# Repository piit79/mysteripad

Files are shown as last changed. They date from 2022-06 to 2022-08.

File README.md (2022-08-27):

# Mysteripad

#### WARNING: This project is a work in progress and hasn't been validated yet.

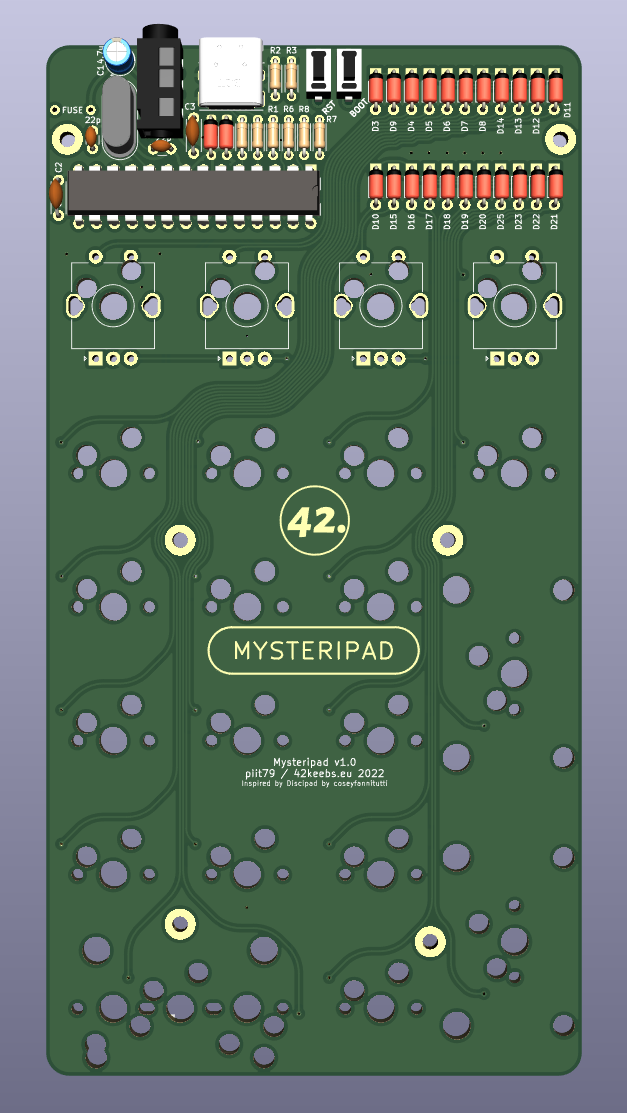
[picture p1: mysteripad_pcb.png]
Mysteripad PCB


Mysteripad is a through-hole numeric keyboard (or "numpad") matching the form 
factor of the [Mysterium keyboard]((https://github.com/piit79/mysterium)) 
([original](https://github.com/coseyfannitutti/mysterium)), much like the 
[Discipad](https://github.com/piit79/discipad) 
([original](https://github.com/coseyfannitutti/discipad)) matches the 
[Discipline](https://github.com/piit79/discipline) 
([original](https://github.com/coseyfannitutti/discipline)).

Mysteripad was inspired by (but is not based on) the [Discipad](https://github.com/coseyfannitutti/discipad) by Bryan of [cftkb.com](https://cftkb.com/).

## Features

* 17-22 keys, 0-4 rotary encoders (6 rows, 4 columns)
* Hotswappable using Kailh/Gateron hotswap sockets
* All 4 top row positions support either a switch or an EC11 rotary encoder - 4 encoders can be installed at the same time¹
* Optional split 0 support (2x 1u instead of 2u)
* TRRS socket for connection to the next 42. Keebs revision of the Mysterium (V1.5e) via a 4-pin AUX (TRRS) cable (using the I²C bus) so that a single USB cable can be used for both keyboards, similar to split keyboards

¹ To reduce the number of required I/O pins from 8 to 5, any two adjacent encoders share an I/O pin. Therefore, rotating any such encoders at higher speed simultaneously might not work correctly. Other combinations (1-3, 1-4, 2-4) should not be affected.

## Documentation

[Bill of Materials](https://github.com/piit79/mysteripad/tree/main/doc#bill-of-materials)
and [build guide](https://github.com/piit79/mysteripad/tree/main/doc#build-guide) (coming soon)

## Firmware

QMK firmware can be found in [42. Keebs QMK fork](https://github.com/piit79/qmk_firmware/tree/master/keyboards/42keebs/mysteripad).

## Kit availability

You can grab the Gerber zip files from [releases](https://github.com/piit79/mysteripad/releases) 
(coming soon), have the PCBs made at one of the fabs and order all the 
[electronic components](https://github.com/piit79/mysteripad/tree/main/doc#bill-of-materials)
at your favourite electronics store.

A complete kit will also be available from [42. Keebs](https://42keebs.eu/shop/kits/with-discrete-mcu/mysteripad-hotswap-numpad-kit-black-white/) sooner or later (probably in ~~July~~ September 2022).

## TODO

* ~~Add PCB bottom plate~~
* ~~Add PCB switch plate~~
* ~~Add acrylic cover drawing~~
* ~~Create QMK firmware~~
* Add Gerber zip files to releases
* ~~Add BOM~~
* Add build guide

## Revision history

* v1.0 (26/06/2022) - Initial version

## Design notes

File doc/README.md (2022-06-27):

# Mysteripad Documentation

## Bill of Materials

| Reference | Quantity | Description |
|---|---:|---|
| U1 | 1 | ATmega328p-PU microcontroller
| USB1 | 1 | GCT USB4085-GF-A USB-C socket
| J1 | 1 | PJ-320A 3.5 mm 4-pole AUX (TRRS) socket
| Y1 | 1 | 16 MHz crystal
| F1 | 1 | 500 mA resettable fuse (polyfuse)
| C1 | 1 | 4.7 µF electrolytic capacitor RM1.5
| C2, C3 | 2 | 0.1 µF ceramic capacitor RM5.08
| C4, C5 | 2 | 22 pF ceramic capacitor RM2.5
| R1 | 1 | 1.5 kΩ 1/6 W resistor
| R2, R3, R7, R8 | 4 | 5.1 kΩ 1/6 W resistor
| R4, R5 | 2 | 75 Ω 1/6 W resistor
| R6 | 1 | 10 kΩ 1/6 W resistor
| D1, D2 | 2 | 3.6 V Zener diode
| D3-D25 | 22 | 1N4148 diode

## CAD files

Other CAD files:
mysteripad_acrylic_cover.dxf

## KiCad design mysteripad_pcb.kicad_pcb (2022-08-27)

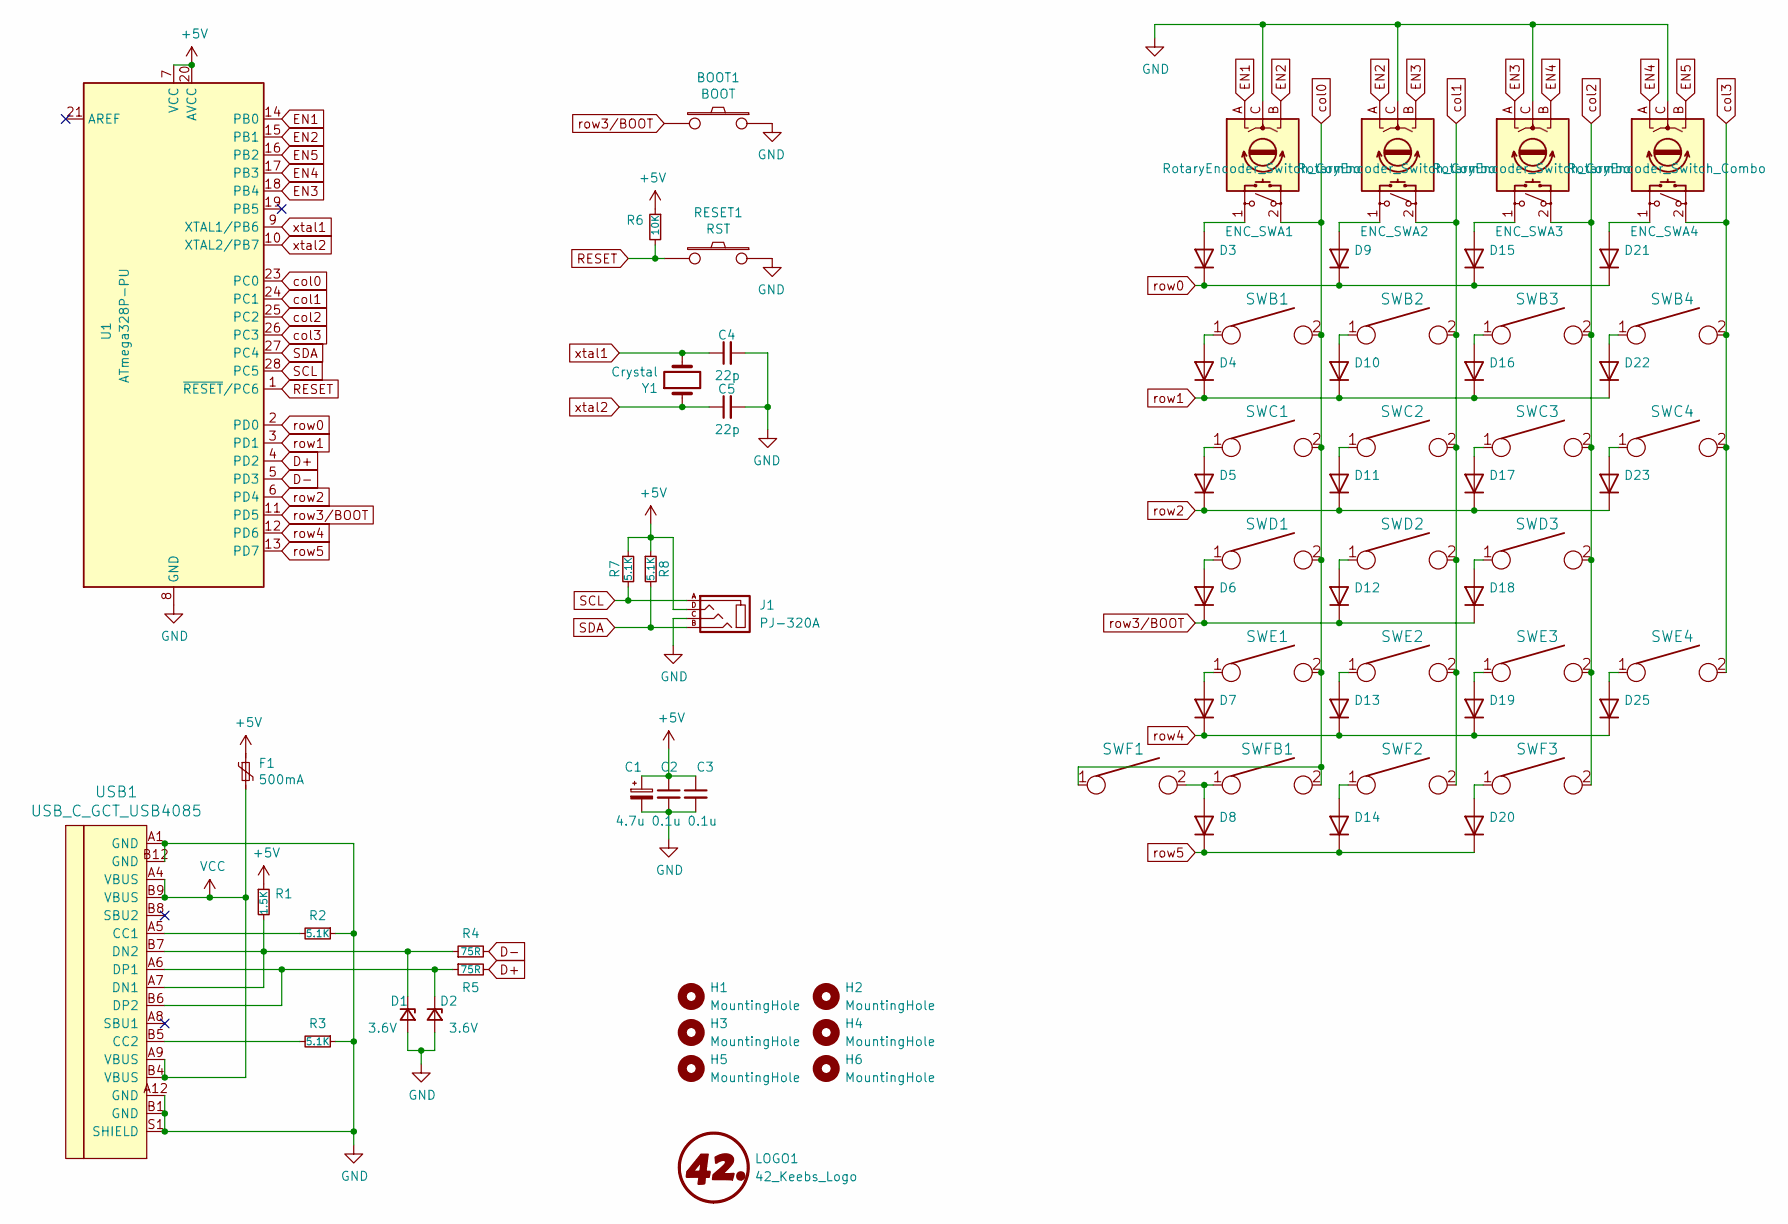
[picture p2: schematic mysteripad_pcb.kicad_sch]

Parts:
BOOT1: BOOT; ResetSW_1side
C1: 4.7u; CP_Radial_D4.0mm_P1.50mm
C2, C3: 0.1u; C_Disc_D4.3mm_W1.9mm_P5.00mm
C4, C5: 22p; C_Disc_D3.0mm_W1.6mm_P2.50mm
D1, D2: 3.6V; ZD_DO-35_SOD27_P5.08mm_Horizontal_smaller
D3, D4, D5, D6, D7, D8, D9, D10, D11, D12, D13, D14, D15, D16, D17, D18, D19, D20, D21, D22, D23, D25: D_DO-35_SOD27_P5.08mm_Horizontal
ENC_SWA1, ENC_SWA2, ENC_SWA3, ENC_SWA4: RotaryEncoder_Switch_Combo; Kailh_MX_Socket-plus-EC11-encoder
F1: 500mA; polyfuse_5.1mm
H1, H2, H3, H4, H5, H6: MountingHole; MountingHole_2.2mm_M2_Pad
J1: PJ-320A
LOGO1: 42_Keebs_Logo; 42Keebs-icon-10mm-Mask
R1: 1.5K; R_Axial_DIN0204_L3.6mm_D1.6mm_P5.08mm_Horizontal
R2, R3, R7, R8: 5.1K; R_Axial_DIN0204_L3.6mm_D1.6mm_P5.08mm_Horizontal
R4, R5: 75R; R_Axial_DIN0204_L3.6mm_D1.6mm_P5.08mm_Horizontal
R6: 10K; R_Axial_DIN0204_L3.6mm_D1.6mm_P5.08mm_Horizontal
RESET1: RST; ResetSW_1side
SWB1, SWB2, SWB3, SWB4: KEYSW; Kailh_MX_Socket-swapped-pads
SWC1, SWC2, SWC3: KEYSW; Kailh_MX_Socket-swapped-pads
SWC4: KEYSW; Kailh_MX_Socket-2u-swapped-pads-reversed-stabilizer
SWD1, SWD2, SWD3: KEYSW; Kailh_MX_Socket-swapped-pads
SWE1, SWE2, SWE3: KEYSW; Kailh_MX_Socket-swapped-pads
SWE4: KEYSW; Kailh_MX_Socket-2u-swapped-pads-reversed-stabilizer
SWF1, SWF2, SWF3: KEYSW; Kailh_MX_Socket-swapped-pads
SWFB1: KEYSW; Kailh_MX_Socket-2u-swapped-pads-reversed-stabilizer
U1: ATmega328P-PU; DIP-28_W7.62mm
USB1: USB_C_GCT_USB4085; USB_C_GCT_USB4085-offset-pads
Y1: Crystal; Crystal_HC49-4H_Vertical

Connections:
+5V: C1.1, C2.1, C3.1, F1.1, J1.D, R1.1, R6.1, R7.1, R8.1, U1.7 (VCC), U1.20 (AVCC)
D+: R5.2, U1.4 (PD2)
D-: R4.2, U1.5 (PD3)
EN1: ENC_SWA1.A, U1.14 (PB0)
EN2: ENC_SWA1.B, ENC_SWA2.A, U1.15 (PB1)
EN3: ENC_SWA2.B, ENC_SWA3.A, U1.18 (PB4)
EN4: ENC_SWA3.B, ENC_SWA4.A, U1.17 (PB3)
EN5: ENC_SWA4.B, U1.16 (PB2)
GND: BOOT1.1, C1.2, C2.2, C3.2, C4.2, C5.2, D1.2 (A), D2.2 (A), ENC_SWA1.C, ENC_SWA2.C, ENC_SWA3.C, ENC_SWA4.C, J1.C, R2.1, R3.1, RESET1.1, U1.8 (GND), U1.22 (GND), USB1.A1 (GND), USB1.A12 (GND), USB1.B1 (GND), USB1.B12 (GND), USB1.S1 (SHIELD)
unnamed: D1.1 (K), R1.2, R4.1, USB1.A7 (DN1), USB1.B7 (DN2)
unnamed: D2.1 (K), R5.1, USB1.A6 (DP1), USB1.B6 (DP2)
unnamed: D3.2 (A), ENC_SWA1.1
unnamed: D4.2 (A), SWB1.1
unnamed: D5.2 (A), SWC1.1
unnamed: D6.2 (A), SWD1.1
unnamed: D7.2 (A), SWE1.1
unnamed: D8.2 (A), SWF1.2, SWFB1.1
unnamed: D9.2 (A), ENC_SWA2.1
unnamed: D10.2 (A), SWB2.1
unnamed: D11.2 (A), SWC2.1
unnamed: D12.2 (A), SWD2.1
unnamed: D13.2 (A), SWE2.1
unnamed: D14.2 (A), SWF2.1
unnamed: D15.2 (A), ENC_SWA3.1
unnamed: D16.2 (A), SWB3.1
unnamed: D17.2 (A), SWC3.1
unnamed: D18.2 (A), SWD3.1
unnamed: D19.2 (A), SWE3.1
unnamed: D20.2 (A), SWF3.1
unnamed: D21.2 (A), ENC_SWA4.1
unnamed: D22.2 (A), SWB4.1
unnamed: D23.2 (A), SWC4.1
unnamed: D25.2 (A), SWE4.1
unnamed: R2.2, USB1.A5 (CC1)
unnamed: R3.2, USB1.B5 (CC2)
RESET: R6.2, RESET1.2, U1.1 (~RESET/PC6)
SCL: J1.A, R7.2, U1.28 (PC5)
SDA: J1.B, R8.2, U1.27 (PC4)
VCC: F1.2, USB1.A4 (VBUS), USB1.A9 (VBUS), USB1.B4 (VBUS), USB1.B9 (VBUS)
col0: ENC_SWA1.2, SWB1.2, SWC1.2, SWD1.2, SWE1.2, SWF1.1, SWFB1.2, U1.23 (PC0)
col1: ENC_SWA2.2, SWB2.2, SWC2.2, SWD2.2, SWE2.2, SWF2.2, U1.24 (PC1)
col2: ENC_SWA3.2, SWB3.2, SWC3.2, SWD3.2, SWE3.2, SWF3.2, U1.25 (PC2)
col3: ENC_SWA4.2, SWB4.2, SWC4.2, SWE4.2, U1.26 (PC3)
row0: D3.1 (K), D9.1 (K), D15.1 (K), D21.1 (K), U1.2 (PD0)
row1: D4.1 (K), D10.1 (K), D16.1 (K), D22.1 (K), U1.3 (PD1)
row2: D5.1 (K), D11.1 (K), D17.1 (K), D23.1 (K), U1.6 (PD4)
row3/BOOT: BOOT1.2, D6.1 (K), D12.1 (K), D18.1 (K), U1.11 (PD5)
row4: D7.1 (K), D13.1 (K), D19.1 (K), D25.1 (K), U1.12 (PD6)
row5: D8.1 (K), D14.1 (K), D20.1 (K), U1.13 (PD7)
xtal1: C4.1, U1.9 (XTAL1/PB6), Y1.2
xtal2: C5.1, U1.10 (XTAL2/PB7), Y1.1

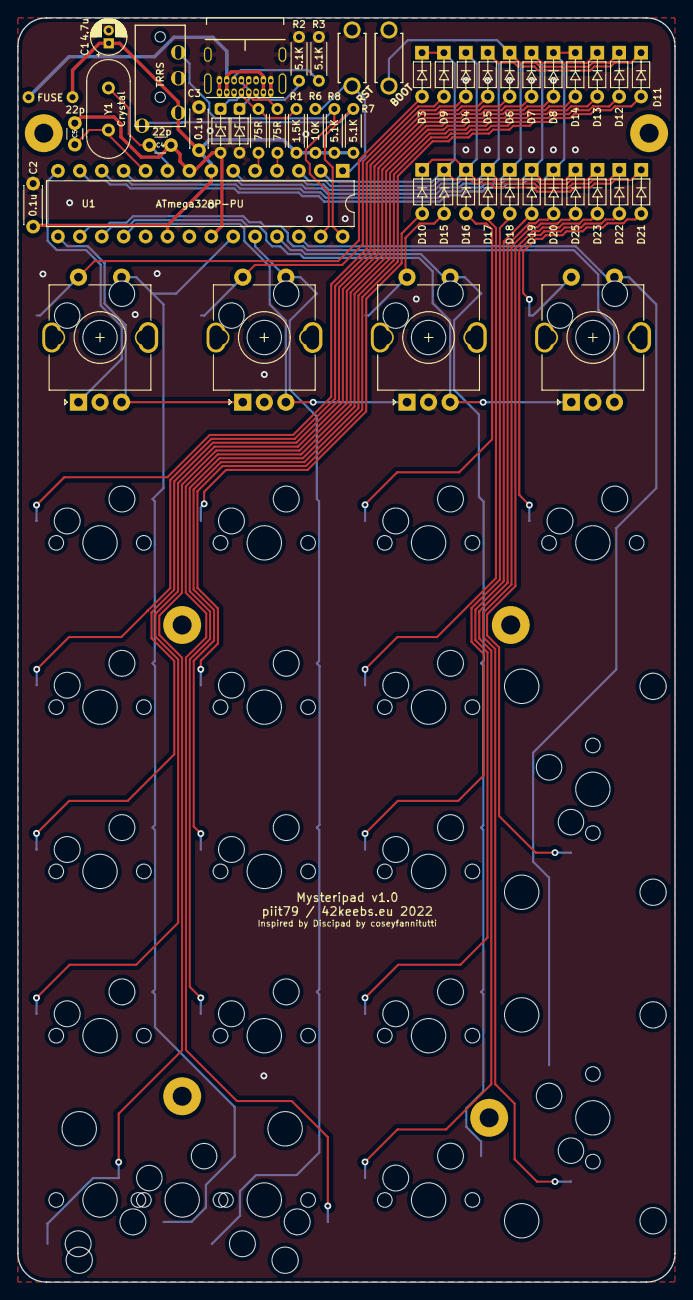
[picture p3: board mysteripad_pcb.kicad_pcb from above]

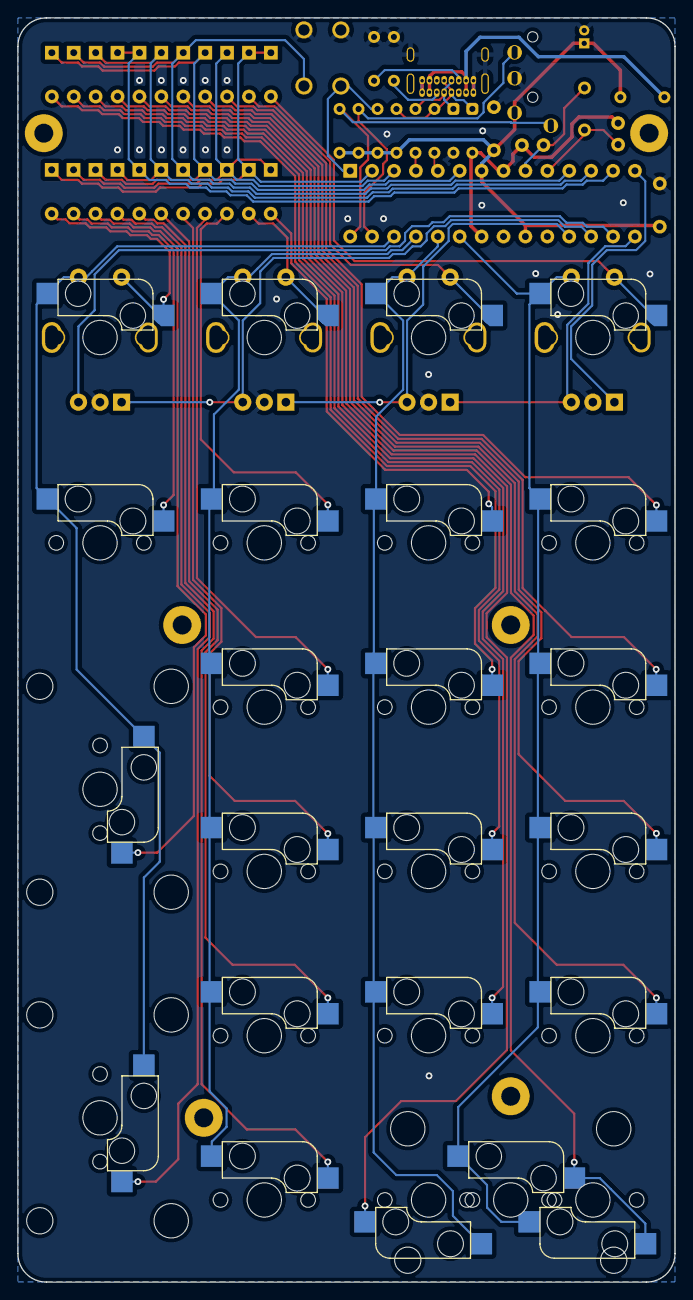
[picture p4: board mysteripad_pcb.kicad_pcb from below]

Board: 2 copper layers, 76.2 x 146.6 mm, 74 parts (19 on the bottom side), 51 nets.

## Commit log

2022-06-25 Add 42. Keebs KiCad library as submodule
2022-06-25 Add kbd KiCad library as submodule
2022-06-26 Initial version v1.0 of the PCB
    [mysteripad_pcb.kicad_pcb, mysteripad_pcb.kicad_sch]
2022-06-27 Add PCB bottom plate
    [mysteripad_bottom.kicad_pcb]
2022-06-27 Add PCB switch plate
    [mysteripad_plate.kicad_pcb]
2022-06-27 Add acrylic cover drawing
    [mysteripad_acrylic_cover.dxf]
2022-06-27 Add BOM
2022-06-27 Update 42. Keebs lib and update footprints with 3D models
    [mysteripad_pcb.kicad_pcb]
2022-07-10 Clean up/improve routing
    [mysteripad_pcb.kicad_pcb]
2022-07-10 Fix RESET/BOOT silkscreen
    [mysteripad_pcb.kicad_pcb]
2022-07-11 Optimize routing for rounded tracks
    [mysteripad_pcb.kicad_pcb]
2022-07-11 Move MCU and crystal down to avoid fix coutyard overlap
    [mysteripad_pcb.kicad_pcb]
2022-07-11 Finish optimising routing for rounded traces
    [mysteripad_pcb.kicad_pcb]
2022-07-11 Add Gerbers dir to .gitignore; update PCB render
2022-08-27 Fix incorrect USB pullup; fix bottom mounting holes
    [mysteripad_bottom.kicad_pcb, mysteripad_pcb.kicad_pcb, mysteripad_pcb.kicad_sch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]
